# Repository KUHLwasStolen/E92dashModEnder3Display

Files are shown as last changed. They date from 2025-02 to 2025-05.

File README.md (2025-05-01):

# open-eye-drive-screen
I have the old LCD from my Creality Ender 3 Pro, which I don't need anymore, because I'm running it headless with Klipper and I want to use it to display some additional information on the dash of my BMW E92.  
Additionally the project comes with an optional/modular data logger addon, to record the sniffed telemetry data.  

The project should be compatible with all cars from the E9x series, but I only have access to an E92 for testing.  

Please make sure to not get distracted by this awesome project while on the road. Always drive with an *open-eye* :)  

On the left you can see the receiver/LCD module mounted in the car and on the right the sender/logging module mounted in the trunk of my E92.  
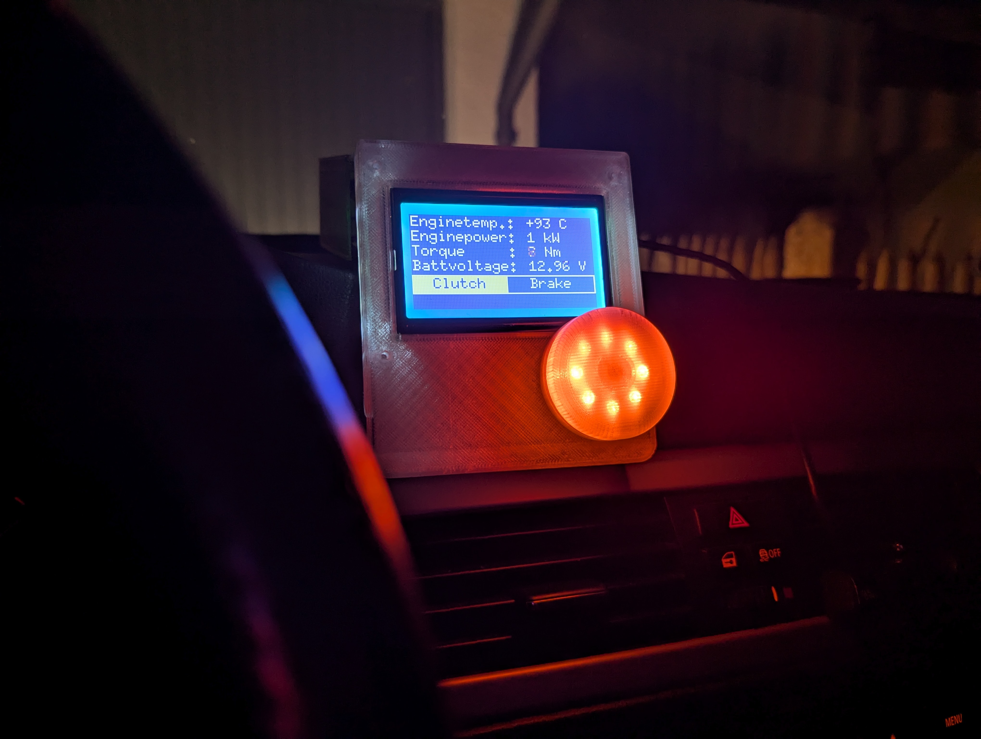
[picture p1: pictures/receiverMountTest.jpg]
picture of the receiver module mounted in the car
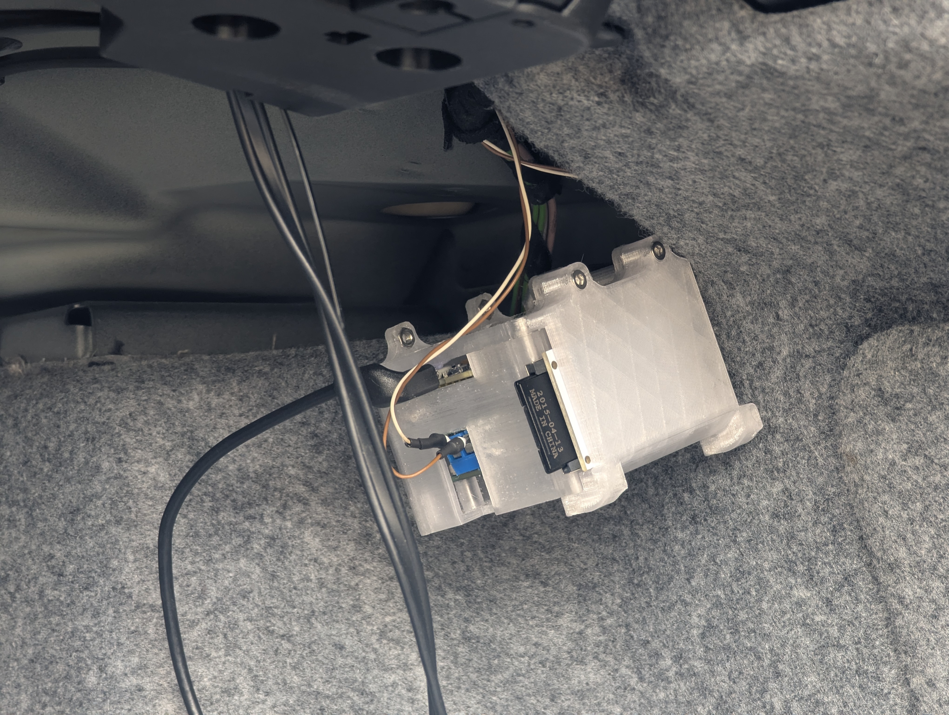
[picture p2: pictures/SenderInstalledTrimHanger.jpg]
picture of the installed sender module
   
The sender is responsible for sniffing the CAN-messages and converting them into numbers and the receiver displays those numbers. Various different pages with different numbers/representations are offered.  
The data is sent via ESP-NOW.  
The sender module is also responsible for logging the data if wished.  
The project is somewhat modular, as you can choose to omit logging capabilities and the LED ring on the encoder knob. You can still use the same code.  

Here is some logged sample data.  
The x-axis represents the time in seconds from when the drive started and the y-axis is longitudinal acceleration in m/s².
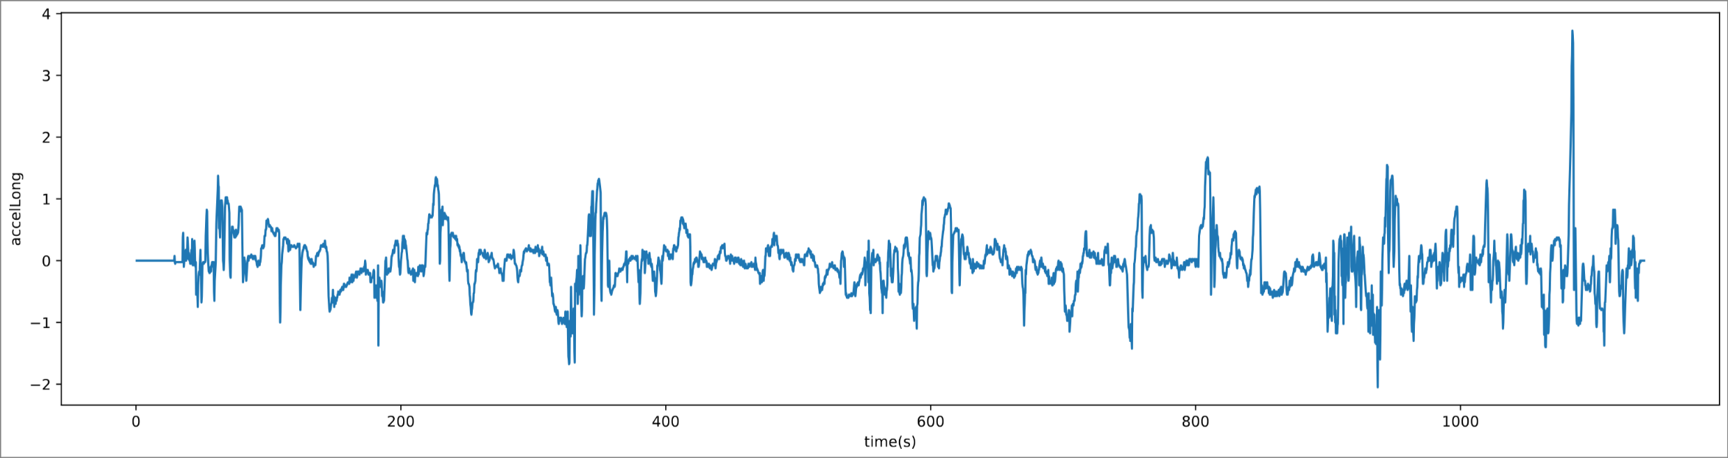
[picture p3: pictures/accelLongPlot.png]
plot of longitudinal acceleration
  
*(newer plots will automatically mark min/max values, see below)*

And this is a small part of an engine-power plot in kW.  
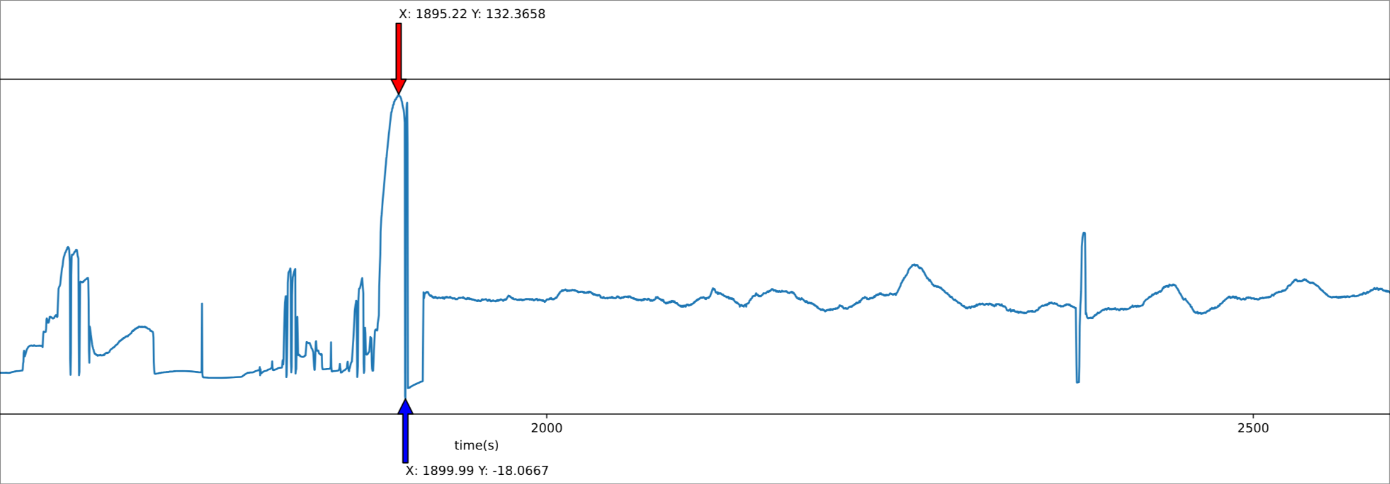
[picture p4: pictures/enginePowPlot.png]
plot of engine power data
  
Notice the annotated minimum and maximum values.  
The data plotter program will automatically do this for you and will also automatically not do this for plots where a min/max value makes no sense.  
Also notice how the minimum value is negative. This is not an error and means that the engine is slowing down the car which typically happens when you are in gear and no throttle is applied.  

## !!!Disclaimer!!!
Modifying the electrical system of your car can be **dangerous** and may void your warranty!  
Dangerous not only for your car, but also for your health!  
Before attempting any of the described modifications in this repository, **fully** read and **fully** understand everything in this README.  
I do **not** take responsibility for any type of damages, that may occur as a result of the modifications shown here.  
Do this at your own risk.

## Additions to the ecosystem  
My plan is to eventually extend this system with more devices in the car.  
Once these projects are started I will link them here.  
Planned (in that order):  
- [Wireless "scroll wheel"](https://github.com/KUHLwasStolen/open-eye-drive-scroller)
    - *BMW iDrive*-inspired controller for the LCD
    - uses a magnetic encoder to "replace" the low-quality one on the LCD
    - dedicated media buttons
- Bluetooth audio adapter
    - Bluetooth to AUX media player
    - optionally integrates into the system to be controlled by other devices and even the car (through the other devices/detected buttons presses/...)
    - (will most-likely require the "scroll wheel" for integration into the system as we cannot use Bluetooth and ESP-NOW at the same time)
- Lap timer
    - standalone lap timer using GPS
    - can record tracks, provide real-time time-delta, etc.
    - integration into system possible

## Plan
The plan is to tap into the CAN-bus somewhere on the vehicle to gather interesting information.  
From my research it seems the best bus to tap into is the KCAN (Karosserie-CAN = Body-CAN), because it contains the most interesting information.  
The speed of the bus is 100 kbit/s and it can be recognized by its twisted pair of orange/green and green wires, where OR/GN stands for CAN-HIGH and GN for CAN-LOW.  

On my vehicle the easiest place to tap into KCAN seems to be by the rear PDC (park distance control) module.  
This module might not be installed on your car.  
Alternatives include the iDrive and ultrasonic overhead alarm sensor, which are both not installed nor pre-wired on my car.  
The only problem with the PDC is that it is mounted in the trunk of the car and I want the information on the dash of my car...  

To solve this problem I want to have an ESP32 in the trunk of the car attached to the KCAN to collect data.  
Then I want another ESP32 with the LCD on the dash of the car.  
Communication between them is handled via ESP-NOW.  
This solution avoids having to run long wires through the car and enables us to mount the CAN-sniffer in the best place in each individual car.  
Another advantage is that this allows us to expand the network of devices in the car pretty easily, as we just have to add another receiver which can then handle the data as wished.  
From my testing during development, this approach has been very reliable and also responsive. I have also found similar projects using ESP-NOW, which seems to support my findings.  

#### Relevant information from KCAN
| CAN-ID | Description | Successful? |
|---|---|---|
| 0x0A8 | Engine torque to compute power, brake and clutch status | **Yes** |
| 0x0AA | Throttle position, engine RPM | **Yes** |
| 0x0C8 | Steering wheel angle/position | **Yes** |
| 0x0CE | Wheel speeds | **Yes** |
| 0x1A0 | Vehicle speed, acceleration | **Yes** |
| 0x1C2 | PDC (park distance control) sensors | **Yes** |
| 0x1D0 | Engine-temperature, (intake) air pressure | **Yes** |
| 0x1D6 | Steering wheel buttons, as not all of them do something in my car | **Yes**, except for disk button (not a top priority though) |
| 0x2F8 | Time and date information | **Yes** |
| 0x330 | Range | **Yes** |
| 0x349 | Fuel level sensors (car has two) | **Yes** |
| 0x362 | Average fuel consumption, avg. speed | **Yes** |
| 0x3B0 | Reverse gear status | **Yes** |
| 0x3B4 | Battery voltage | **Yes** |

## Execution of the plan
Tapping into the KCAN in the trunk of the car was successful.  
I have received all of the expected IDs and the data seems to be accurate/converted properly, which I still have to verify in more detail.  
**Tip:** If you are attempting the same procedure as me, remove the trim panels in the battery area, not only the battery cover.  
I did not and it was *very* tedious due to the space constraints (2 hours for splicing 2 wires).  
**ALSO: Keep away from the black/yellow twisted pair cables going to the battery. They are there for disconnecting the battery in an emergency and should not be messed with!**

At the moment I get the power for the ESP32 with the MCP from the 12V connector in the trunk.  
This connector is on when the ignition is on.  
This is a very convenient solution, but not perfect.  
Because of the (optional) logging system it would be an advantage if the ESP could stay on for a bit after the car is turned off to close the log file.  
Additionally I would like to display a summary of the drive after the car is turned off.  
I know that there are power lines in the BMW that stay on for a while after the car is locked, but I couldn't find much information about this.  
But for now, losing at max a few seconds at the end of the log is fine.  
An alternative would be a small battery backup that keeps the ESP alive for a moment after the car is stopped.  
I'm not a fan of an actual battery, but capacitors might do the trick(?).  

**Attention:** When I first tried to access the KCAN the car was throwing **all** sorts of error messages at me.  
I assume that the cause for this was, that the ESP was sending acknowledgement messages to the car when a message was received.  
Seemingly the car does not like this **at all**. Setting the MCP mode to listen-only seems to fix this though.

## Schematic
The KiCAD schematic in this repository serves a purely symbolic purpose!  
I am not an expert at designing circuits and just want to give you a general idea about the correct wiring.  
Any constructive input on how to improve the schematic is greatly appreciated!

## 3D Models
3D-printable enclosures and accessories can be found [here](cad/exports).  
(Yes, most slicers are able to use .step files, most people are not aware of this).  
All of the models are in their perfect printing orientation and do not *need* supports.  
The only place where you might need a tiny bit of support is [this](cad/exports/SenderModels/Enclosure_bottom.step) model, on the small, straight overhang for the screw terminal.  
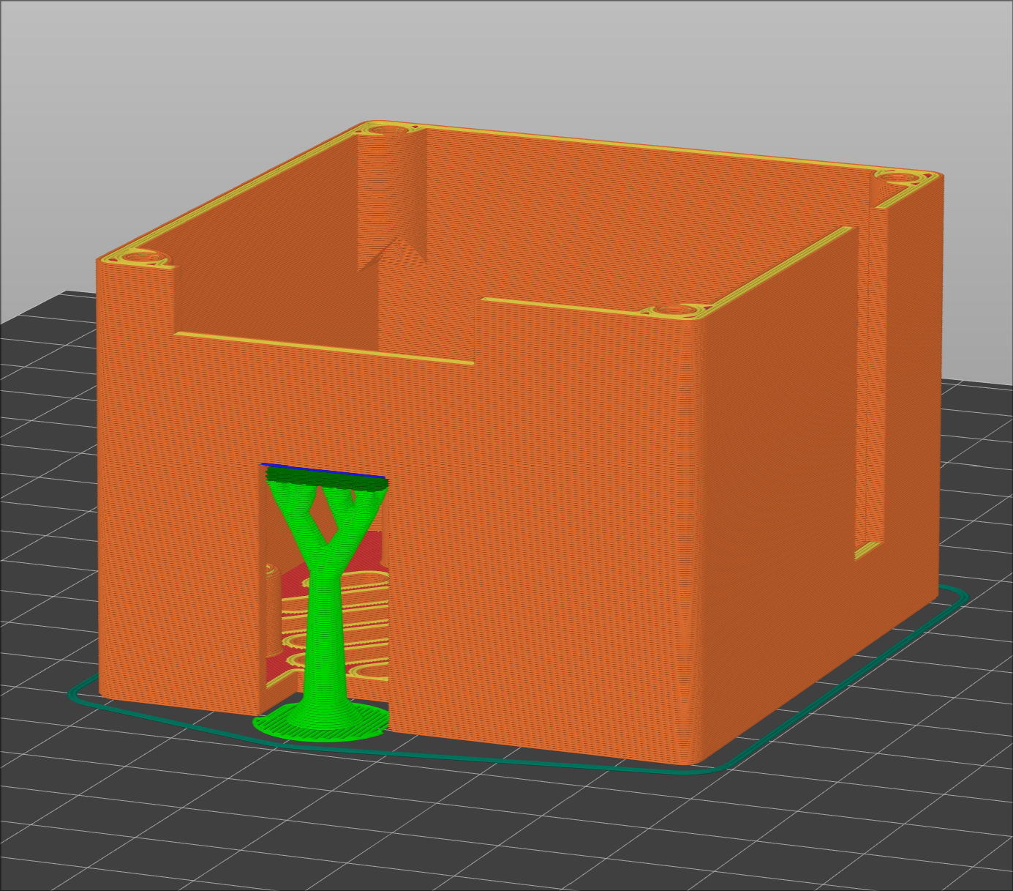
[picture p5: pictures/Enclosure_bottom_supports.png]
Enclosure_bottom support example
  

The models include a lot of screw holes which are made to be tapped.  
Ideally you would use a thread tap for this, but you can also probably just cut the thread by screwing in the bolt that is supposed to go there.  
Tapped threads in 3D-prints are surprisingly strong and durable. They are a great way to easily put threads in all kinds of places/orientations.  

## Logging
As mentioned above, the project offers optional logging capability.  
Data is stored to a SD-card in .csv format. For space reasons non-floating-point values in HEX, so not really human readable or ready to easily plot.  
The project offers a C++ program to convert the data back into decimal form, which is located [here](logging).  

*Usage:*  
```
# first compile the program (only needed once)
g++ dataConverter.cpp -o dataConverter

# then convert your log
./dataConverter [your_log.csv]
```

Then you can plot the converted data into a PDF with the python script in the same folder.  
The x-axis will always be the time in seconds since the drive started.  

*Usage:*
```
# index: 0 -> time(s), 1 -> clutchPressed, 2-> brakePressed, ...
python dataPlotter.py [your_log_converted.csv] [column index to plot on y]

# or to plot all columns and export them into separate files
python dataPlotter.py [your_log_converted.csv] all
```

## Hardware
Here you can find a list of materials needed for the project.  
Note that this list always reflects the current state of the project and might change over time.  
Also note that links to products are only meant as a guide what to look for and what/where ***I*** bought them.  
Depending on your location/preference there might be better/cheaper alternatives.  
You can buy the components wherever you want as long as they are the same/similar enough.  
I am in no way affiliated with the linked sellers and can in no way guarantee their reliability!  

| Description | Quantity | Notes | Link |
|---|---|---|---|
| ESP32-WROOM-32 dev module | 2 | most other ESPs should also work, just connect everything to the right GPIOs | https://www.az-delivery.de/en/products/esp32-developmentboard?_pos=1&_psq=esp32+n&_ss=e&_v=1.0 |
| MCP2515 CAN bus module | 1 | yes, odd choice in combination with ESP32, I just use what I already had | https://www.az-delivery.de/en/products/mcp2515-can-bus-modul?_pos=1&_psq=MCP2515&_ss=e&_v=1.0 |
| Ender 3 (Pro) LCD | 1 | also an odd choice but, again, I already had one from my 3D printer; I will not leave a link where to buy one as this doesn't make much sense, it would be easier/cheaper to just implement support for other types of displays, which is also planned for the future! | |
| (SD card module) | (1) | OPTIONAL: this is an optional feature to log the collected telemetry, this can also be added later and doesn't need a code update | https://www.velleman.eu/products/view/sd-card-logging-shield-for-arduino-2-pcs-vma304/?id=435522&lang=en (I have exactly these, didn't buy them there though) |
| (SD card) | (1) | if you want to use the optional data logger you will need an SD card |  |
| (WS2812 LED ring 8 pixels) | (1) | OPTIONAL: used to light up the encoder knob on the LCD and play animations | https://www.az-delivery.de/en/products/led-ring-ws2812-5050-rgb?variant=44246024978699 |
| 10k Ohm resistor | 3 | used as pullups, similar values may also work |  |
| 560 Ohm resistor | 2 | used for the transistors, similar values may also work |  |
| (330 Ohm resistor) | 1 | used for the optional LED ring, similar values also work |  |
| BC547 transistor | 1 | used to switch LCD on/off, can be replaced by a similar NPN |  |
| S8550 transistor | 1 | used to switch LCD on/off, can be replaced by a similar PNP |  |
| M3x6 bolts | 0-4 | Depending on config: used to mount the trim hook, SD card cover on the bottom |  |
| M3x8 bolts | 4-7 | Depending on config: used for the SD card breakout board, mounting the MCP |  |
| M3x10 bolts | 0-2 | Depending on config: used to hold SD card cover |  |
| M3x12 bolts | 4-5 | Used for attaching the sender lid and the optional LED ring cover/holder |  |
| M3 hex nuts | 0-9 | Depending on config: used for the SD card breakout board, accessory mounting |  |
| (Jumper) wires | 1 metric ton | jumper wires for testing on a bread board |  |
| Perf board + accessories |  | for the final implementation in the enclosures in the car | https://www.amazon.com/Smraza-Soldering-Electronic-Compatible-Prototype/dp/B07NM68FXK/ref=sr_1_3 (I bought something similar) | 

## References
Here you can find some links with useful information in relation to this project.  

**CAN bus related**
| Description | Link |
|---|---|
| This thread contains **A LOT** of information about the E9x KCAN, but it is also kind of all over the place so you have to dig a bit | https://www.e90post.com/forums/showthread.php?t=177272 |
| Awesome work on decoding the BMW K-CAN bus system. But watch out, this work wasn't done on an E9X so CAN IDs and formulas *may* differ but should largely be the same. | https://www.loopybunny.co.uk/CarPC/k_can.html |
| Another project decoding the BMW CAN bus, although it says PT-CAN I found a lot of overlap between the K- and PT-CAN | https://github.com/HeinrichG-V12/E65_ReverseEngineering |
| A table I found with CAN bus IDs of the E9X and their meanings | https://github.com/kmalinich/node-bmw-ref/blob/master/canbus/e90-tool32-ids.csv |

**Hardware related**
| Description | Link |
|---|---|
| My source for the Ender3 LCD pinout | https://github.com/rfblock/ender3-lcd-arduino |
| Library used to drive LCD (can be downloaded via Arduino IDE) | https://github.com/olikraus/u8g2 |
| Library used to drive MCP2515 module (can be downloaded via Arduino IDE) | https://github.com/Seeed-Studio/Seeed_Arduino_CAN |
| Library used to drive the LED ring (can be downloaded via Arduino IDE) | https://github.com/adafruit/Adafruit_NeoPixel |

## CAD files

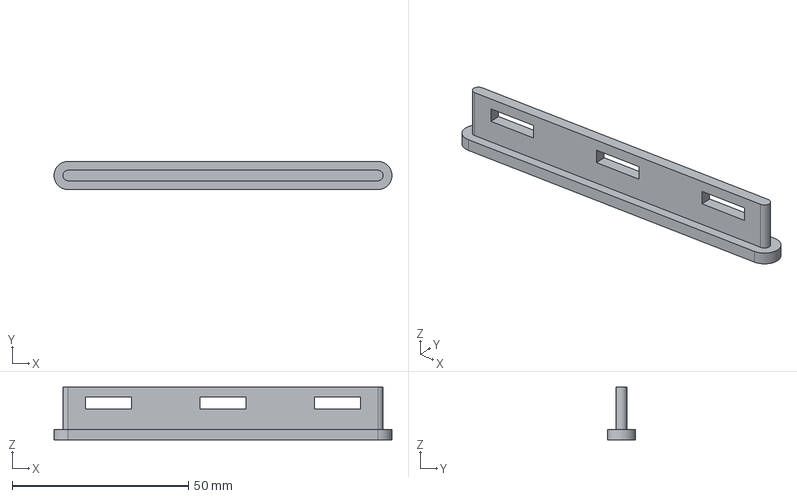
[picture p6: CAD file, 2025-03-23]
cad/exports/ReceiverModels/velcro_ties_mount.step
95.9 x 8.00 x 15.0 mm

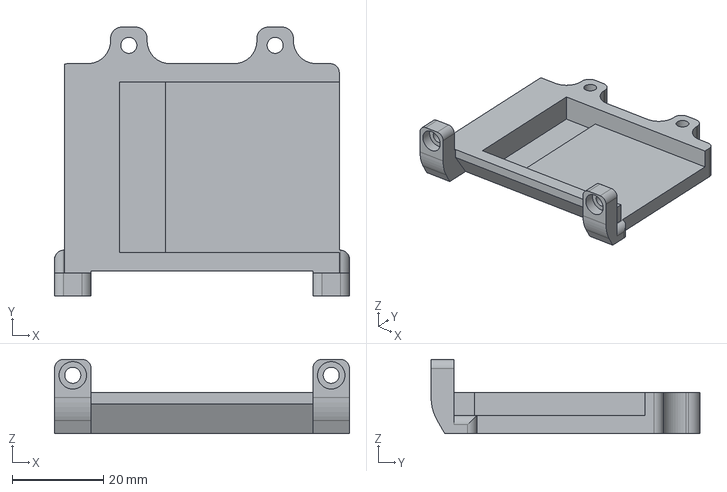
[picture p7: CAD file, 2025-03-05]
cad/exports/SenderModels/SD_cover.step
64.5 x 58.8 x 16.3 mm

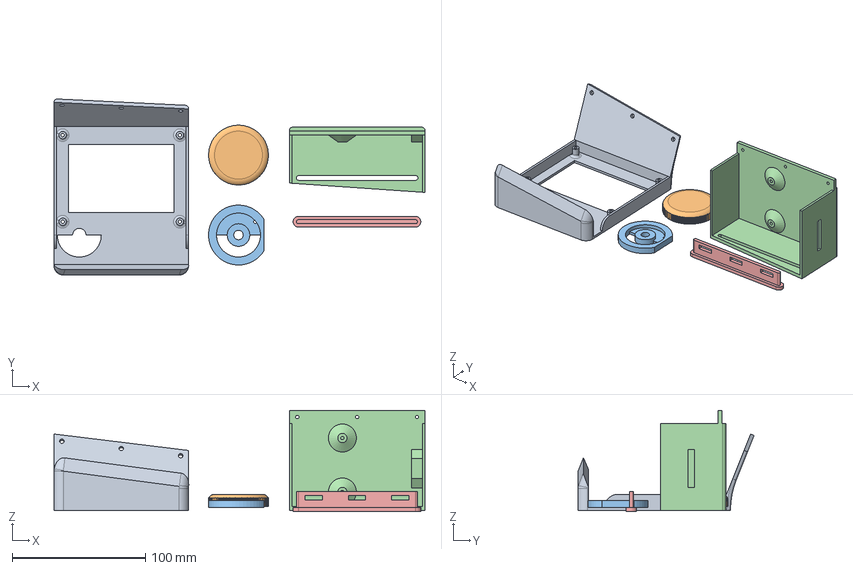
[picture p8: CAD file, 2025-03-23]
cad/ReceiverModels/ReceiverModels.FCStd
278.5 x 132.1 x 76.0 mm
LCD mount
Encoder knob
LED ring holder
Controller enclosure
Controller mounting velcro ties

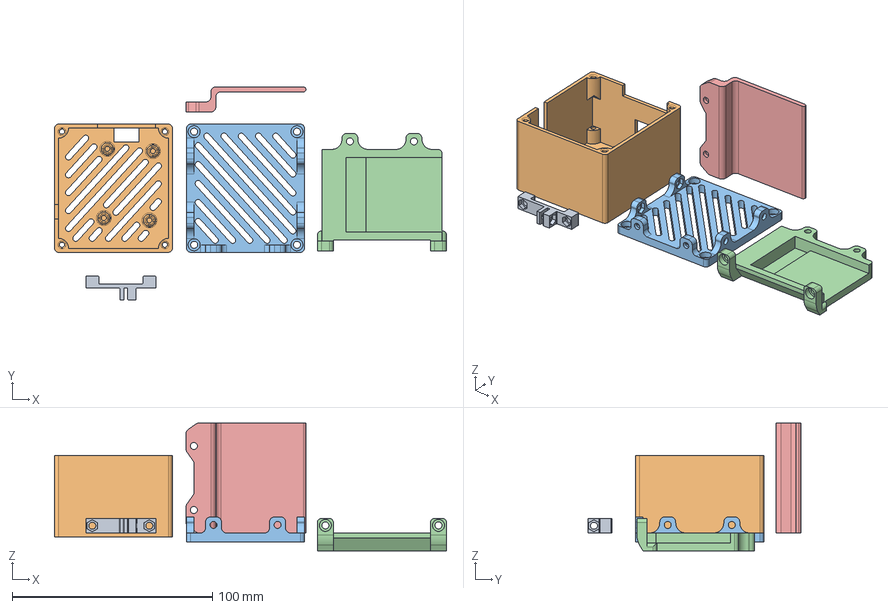
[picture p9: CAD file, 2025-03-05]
cad/SenderModels/SenderModels.FCStd
195.9 x 106.5 x 63.9 mm
SD breakout holder
Enclosure bottom
Enclosure top
SD cover
E92 trim hanger

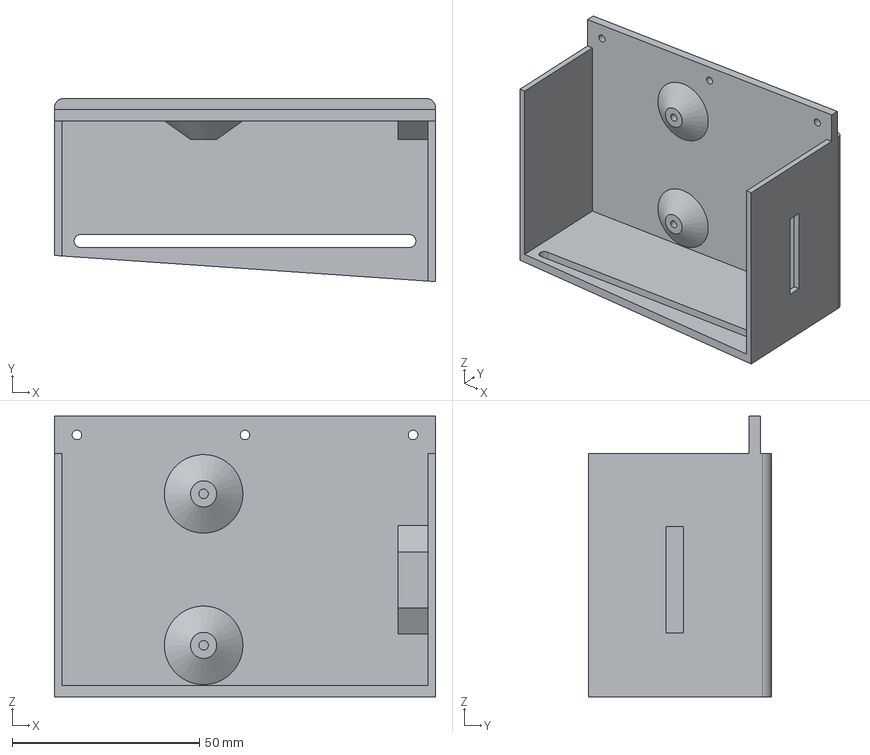
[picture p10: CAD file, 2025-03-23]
cad/exports/ReceiverModels/controller_enclosure.step
101.9 x 49.0 x 75.0 mm

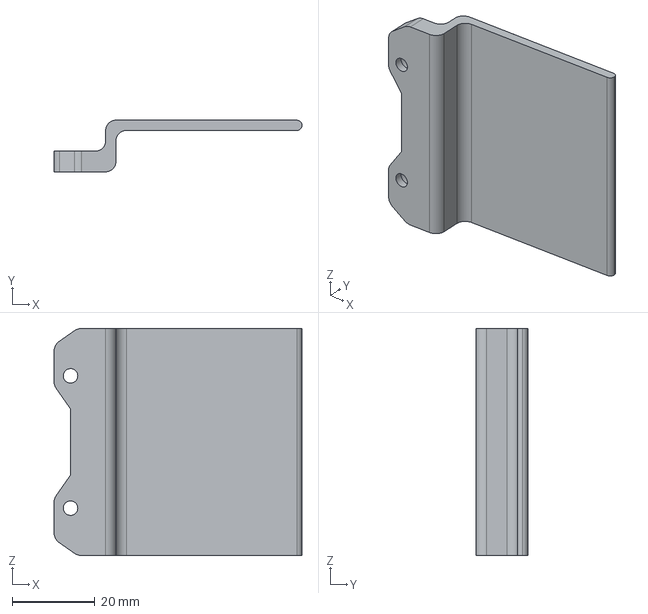
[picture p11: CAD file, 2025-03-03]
cad/exports/SenderModels/E92_trim_hanger.step
60.0 x 12.5 x 54.9 mm

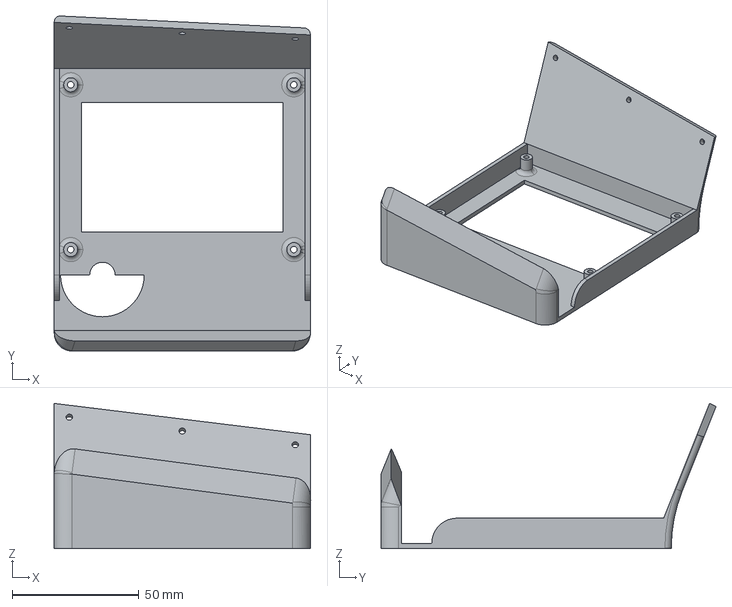
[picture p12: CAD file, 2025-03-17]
cad/exports/ReceiverModels/LCD_mount.step
101.2 x 132.1 x 57.3 mm

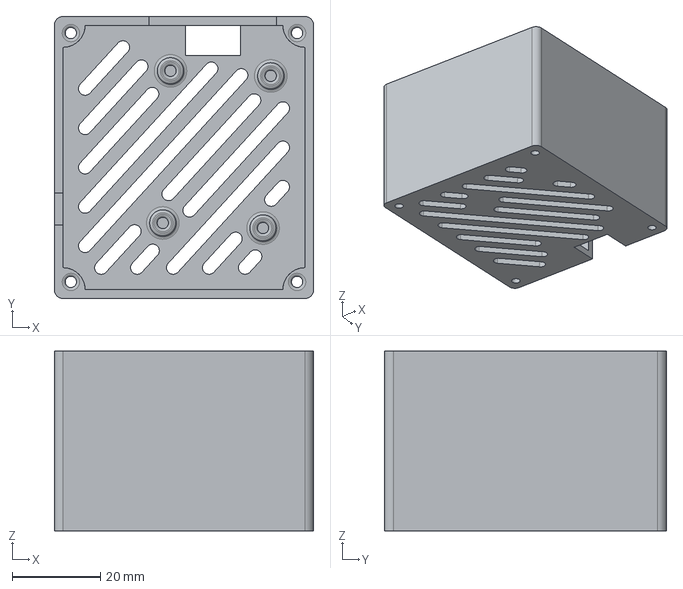
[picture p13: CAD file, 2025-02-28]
cad/exports/SenderModels/Enclosure_bottom.step
58.9 x 64.1 x 40.8 mm

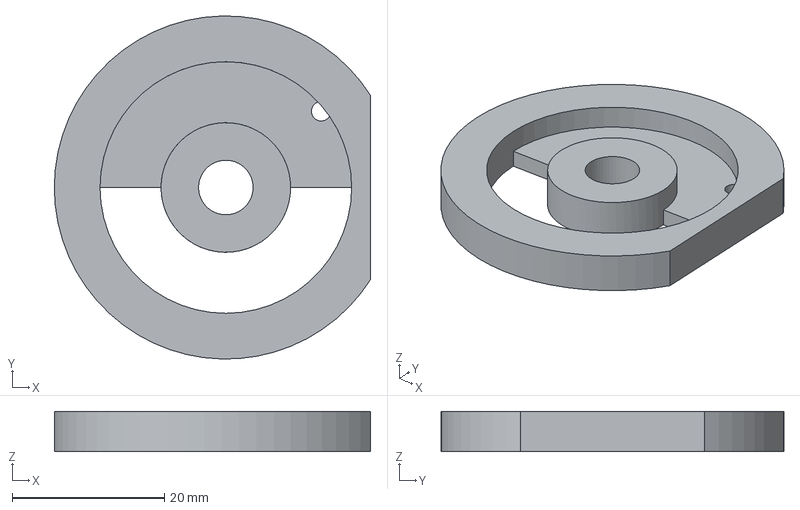
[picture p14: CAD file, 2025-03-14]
cad/exports/ReceiverModels/LED_ring_holder.step
41.5 x 45.0 x 5.25 mm

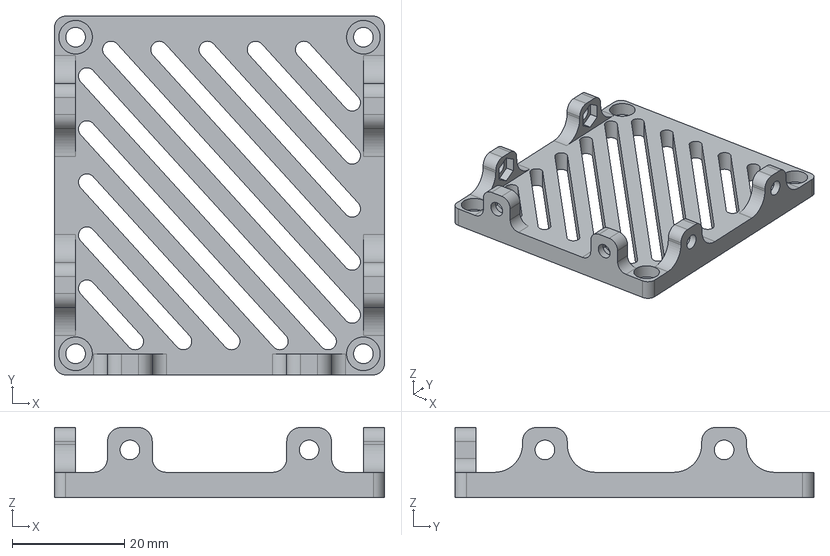
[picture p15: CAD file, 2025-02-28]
cad/exports/SenderModels/Enclosure_top.step
58.9 x 64.1 x 12.5 mm

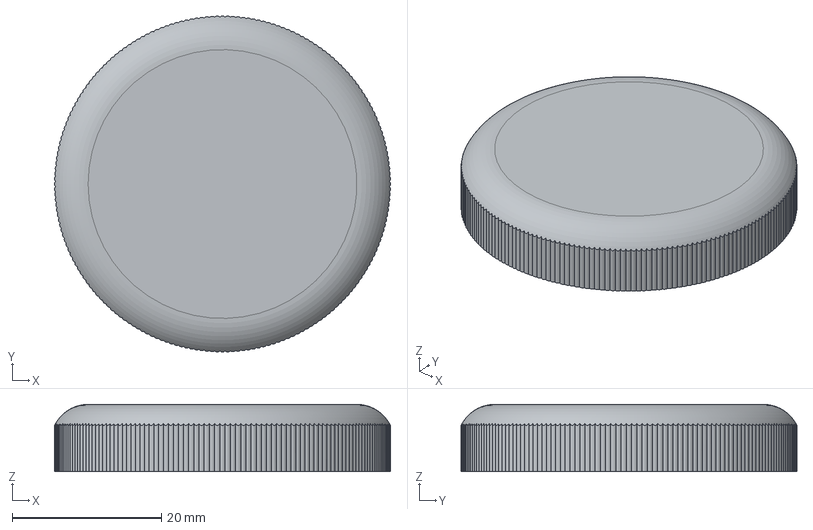
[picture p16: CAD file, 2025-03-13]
cad/exports/ReceiverModels/encoder_knob.step
45.0 x 45.0 x 9.00 mm

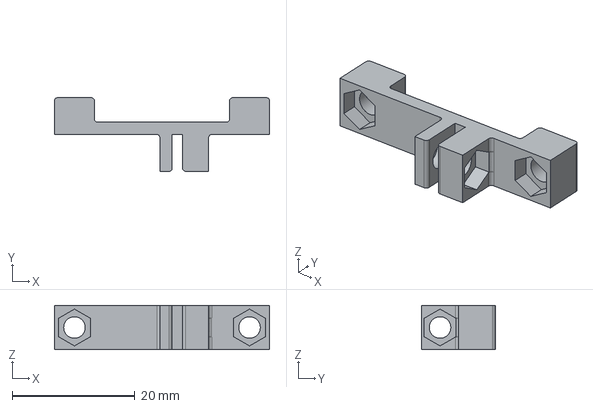
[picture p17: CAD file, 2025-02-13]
cad/exports/SenderModels/SD_holder.step
35.0 x 12.0 x 7.20 mm

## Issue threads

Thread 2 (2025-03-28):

Weird rendering behaviour

KUHLwasStolen, 2025-03-28:
The first line of the selector screen is weirdly rendered if the standard LCD screen setting is not the mixed dash.
Switching the LCD off and on again fixes this.

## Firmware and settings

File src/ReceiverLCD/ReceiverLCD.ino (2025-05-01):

#include <esp_now.h>
#include <WiFi.h>
#include <SPI.h>
#include <U8g2lib.h>
#include <Adafruit_NeoPixel.h>
#include <Preferences.h>

#define EN2_PIN 23
#define EN1_PIN 22
#define ENC_PIN 21

#define LCD_POWER_PIN 13
#define LCD_CS_PIN 15
#define LCD_SCK_PIN 14
#define LCD_MOSI_PIN 27

#define LED_RING_PIN 26
#define PIXEL_COUNT 8

// ## LCD related
#define LCD_OFF_STATE 0
#define MIXED_DASH_STATE 1
#define SPEED_ACCEL_STATE 2
#define FUEL_INFO_STATE 3
#define PDC_SENSOR_STATE 4

U8G2_ST7920_128X64_F_SW_SPI u8g2(U8G2_R0, LCD_SCK_PIN, LCD_MOSI_PIN, LCD_CS_PIN);
uint8_t lcdState = 1; // see state numbers and meanings above
uint8_t standardLcdState = lcdState; // used for displaying/setting standard state
#define LCDSTATE_COUNT 5 // number of available states of the lcd (another one is added automatically, selector screen)
#define MAX_LINES 7 // max number of selectable line
uint8_t selectedLine = 0; // for screens that use user selection

// ## LED ring related
Adafruit_NeoPixel ledRing(PIXEL_COUNT, LED_RING_PIN, NEO_GRB + NEO_KHZ800);
const uint32_t standardColor = ledRing.Color(0xFE, 0x81, 0x06);
uint8_t ledRingState = 1; // 0 = off, 1 = static standard color, ... (refer to updateLedRing() function)
#define LEDSTATE_COUNT 3

uint8_t ledBrightness = 70; // brightness of led ring from 0 (off) to 255 (full), going too high is not recommended because of power draw and danger of being blinded
const uint8_t maxLedBrightness = 140; // limits the brightness of the LED ring to a reasonable level (used for adjusting via LCD)
const uint8_t ledBrightnessStep = 7; // steps for increasing ledBrightness

#define MAXPOW_RPM 4000 // used for shift indicator, adjust this for your own car, refer to spec sheets online or use the data logger of the sender module to find this point
#define SHIFTINDICATOR_START 2000 // this is the rpm where the shift indicator will illuminate the first light
// individual color steps of the led ring gear shift indicator
const uint32_t gearShiftColors[PIXEL_COUNT] = {ledRing.Color(0x2E, 0xFF, 0x11), ledRing.Color(0xB6, 0xFF, 0x00), ledRing.Color(0xFF, 0xF6, 0x00), ledRing.Color(0xFF, 0xE0, 0x30), ledRing.Color(0xFF, 0xE0, 0x30), ledRing.Color(0xFF, 0xD5, 0x00), ledRing.Color(0xFF, 0x60, 0x21), ledRing.Color(0xFF, 0x23, 0x23)};
bool rpmBlinkOn = false;
uint64_t lastBlinkChange = 0;

// ## Preferences/settings related
Preferences preferences;
/* saved settings:
standardValues {
  lcdState: uint8_t
  ledRingState: uint8_t
  ledBrightness: uint8_t
}                         */

// ## Task handles
TaskHandle_t RenderingTask;
TaskHandle_t UserInputTask;

// ## ESP-NOW related
#define ESP_NOW_CHANNEL 1 // if you change this you have to change this on all devices

typedef struct kcan_data_t {
  bool clutchPressed;
  bool brakePressed;
  bool reversed;
  uint8_t steeringWheelButtons; // each bit one button (use functions below): 2^0=VolumeUp, 2^1=VolumeDown, 2^2=UpButton, 2^3=DownButton, 2^4=TelephoneButton, 2^5=VoiceButton, 2^6=RotateButton, 2^7=DiskButton
  uint8_t PDCsensors[8]; // in cm, order: rear-L, rear-L2, rear-R2, rear-R, front-L, front-L2, front-R2, front-R
  int16_t engineTemp; // in celcius
  int16_t wheelSpeeds[4]; // in km/h (might depend on car settings), order: front-L, front-R, rear-L, rear-R
  uint16_t speed; // in km/h (might depend on car settings)
  uint16_t engineRpm;
  uint16_t range; // in km
  uint16_t airPressEngine; // in hPa
  float fuelLevel1; // in liter
  float fuelLevel2; // in liter
  float engineTorque; // in Nm, can be negative!
  float batteryVoltage; // in volts
  float avgConsumption; // in l/100km (dependent on the car settings)
  float avgSpeed; // in km/h (dependent on the car settings)
  float throttlePercentage; // throttle from 0 (foot off paddle) to 1 (flat), also includes throttle input from cruise control
  float steeringPosition; // +1 -> fully (600°) to the left, 0 -> centered, -1 -> fully (600°) to the right
  float accelerationLong; // in m/s²
  float accelerationCross; // in m/s²
} kcan_data_t;

typedef struct sd_data_t {
  uint16_t usedMiB;
  uint16_t totalMiB;
} sd_data_t;

typedef struct scroller_data_t {
  int8_t rotation; // positive -> clockwise steps, negative -> counter-clockwise steps
  uint8_t buttons; // each bit one button (use functions below): 2^0=pause, 2^1=next, 2^2=prev, 2^3=click, 2^4=right, 2^5=left
} scroller_data_t;

kcan_data_t kcan_data;
sd_data_t sd_data = {0, 0};
scroller_data_t scroller_data = {0};

// executed when data is received
void OnDataRecv(const uint8_t * mac, const uint8_t * incomingData, int32_t len) {
  if(len == sizeof(kcan_data)) {
    memcpy(&kcan_data, incomingData, sizeof(kcan_data));
  } else if(len == sizeof(sd_data)) {
    memcpy(&sd_data, incomingData, sizeof(sd_data));
  } else if(len == sizeof(scroller_data)) {
    memcpy(&scroller_data, incomingData, sizeof(scroller_data));
  }
}


void setup() {
  Serial.begin(115200);

  pinMode(LCD_POWER_PIN, OUTPUT);
  pinMode(ENC_PIN, INPUT);
  pinMode(EN1_PIN, INPUT);

  digitalWrite(LCD_POWER_PIN, HIGH); // turn on lcd
  

  u8g2.begin(); // initialize lcd
  u8g2.setFont(u8g2_font_6x10_mr);
  u8g2.clear();


  // Setup WIFI mode and print MAC address
  WiFi.mode(WIFI_MODE_STA);
  WiFi.setChannel(ESP_NOW_CHANNEL);
  while (!WiFi.STA.started()) {
    delay(100);
  }
  Serial.print("Receiving data at: ");
  Serial.println(WiFi.macAddress());

  // Init ESP-NOW
  if (esp_now_init() != ESP_OK) {
    Serial.println("Error initializing ESP-NOW! Restarting in 250");
    displayErrorMessage("ESP-NOW init failed!");
    delay(250);
    ESP.restart();
  }

  // register callback function
  esp_now_register_recv_cb(esp_now_recv_cb_t(OnDataRecv));
  Serial.println("Succesfully initialized ESP-NOW");
  
  Serial.print("Expecting ESP-NOW messages at a size of: ");
  Serial.println(sizeof(kcan_data));

  ledRing.begin(); // initialize LEDs
  ledRing.show(); // initialize pixels to off

  // get last saved preferences
  preferences.begin("standardValues", true);
  lcdState = preferences.getUChar("lcdState", lcdState);
  standardLcdState = lcdState;
  ledRingState = preferences.getUChar("ledRingState", ledRingState);
  ledBrightness = preferences.getUChar("ledBrightness", ledBrightness);
  preferences.end();

  // display BMW logo and 1 ms later start ledRing animation
  showStartupLogo(1);

  for(uint8_t i = 0; i < 3 * PIXEL_COUNT; i++) {
    ledRing.clear();
    ledRing.setBrightness(ledBrightness);
    ledRing.setPixelColor(i % PIXEL_COUNT, ledRing.gamma32(standardColor));
    ledRing.show();

    delay(83);
  }

  xTaskCreatePinnedToCore(
                    renderingTaskCode,    // Task function
                    "renderingTask",      // name of task
                    10000,                // Stack size of task
                    NULL,                 // parameter of the task
                    2,                    // priority of the task
                    &RenderingTask,       // Task handle to keep track of created task
                    1);                   // pin task to core 1

  xTaskCreatePinnedToCore(
                    userInputTaskCode,    // Task function
                    "userInputTask",      // name of task
                    10000,                // Stack size of task
                    NULL,                 // parameter of the task
                    1,                    // priority of the task
                    &UserInputTask,       // Task handle to keep track of created task
                    1);                   // pin task to core 1
}

 
void loop() {
}


void userInputTaskCode(void * params) {
  Serial.print("User input task running on core ");
  Serial.println(xPortGetCoreID());

  bool pressed = false;

  while(1) {
    // Encoder button
    if(digitalRead(ENC_PIN) == 0 || clickPressed()) {
      pressed = true;
      Serial.println("Encoder/Click button pressed");
      
      // only need to handle states with special cases
      switch(lcdState) {
        case LCDSTATE_COUNT: // selector screen
          switch(selectedLine) {
            case 0: // "Next"
              lcdState = 1; // go back to the first page
            break;

            case 1: // "LCD off"
              Serial.println("Turning off LCD");
              lcdState = 0;
              digitalWrite(LCD_POWER_PIN, LOW);
            break;

            case 2: // "LED mode"
              Serial.println("Switching LED ring state");
              ledRingState = (ledRingState + 1) % LEDSTATE_COUNT;
            break;

            case 3: // "LED brightness"
              Serial.println("Changing LED ring brightness");
              ledBrightness = (ledBrightness + ledBrightnessStep) % (maxLedBrightness + ledBrightnessStep);
            break;

            case 4: // standard LCD state
              Serial.println("Changing standard LCD state");
              standardLcdState = (standardLcdState + 1) % LCDSTATE_COUNT;
            break;

            case 5: // save settings
              Serial.println("Saving settings");
              preferences.begin("standardValues", false);
              preferences.putUChar("lcdState", standardLcdState);
              preferences.putUChar("ledRingState", ledRingState);
              preferences.putUChar("ledBrightness", ledBrightness);
              preferences.end();
            break;

            case 6: // Restart ESP
              Serial.println("Rebooting...");
              ESP.restart();
            break;
          }
        break;
        
        default:
          nextScreen();
      }
    }


    // Encoder rotate (no direction detection only rotate, because direction is VERY inconsistent because of low-quality encoder on the LCD)
    if(digitalRead(EN1_PIN) == 0) {
      pressed = true;
      Serial.println("Rotated");
      selectedLine = (selectedLine + 1) % MAX_LINES;
    }


    // Steering wheel buttons
    if(kcan_data.steeringWheelButtons != 0) {
      pressed = true;

      if(volumeUpPressed()) {
        Serial.println("Volume up (steering wheel) pressed");
      }
      if(volumeDownPressed()) {
        Serial.println("Volume down (steering wheel) pressed");
      }
      if(upPressed()) {
        Serial.println("Up button (steering wheel) pressed");
      }
      if(downPressed()) {
        Serial.println("Down button (steering wheel) pressed");
      }
      if(telephonePressed()) {
        Serial.println("Telephone button (steering wheel) pressed");
      }
      if(voicePressed()) {
        Serial.println("Voice button (steering wheel) pressed");
      }
      if(rotatePressed()) {
        Serial.println("Rotate button (steering wheel) pressed");
      }
      if(diskPressed()) {
        Serial.println("Disk button (steering wheel) pressed");
      }
    }


    // Scroller module events
    if(scroller_data.rotation != 0) {
      if(scroller_data.rotation < 0 && -scroller_data.rotation > selectedLine) {
        selectedLine = 0;
      } else {
        selectedLine = min(MAX_LINES - 1, selectedLine + scroller_data.rotation);
      }

      scroller_data.rotation = 0;
    }

    if(scroller_data.buttons != 0) {
      pressed = true;

      if(rightPressed()) {
        nextScreen();
      }
      if(leftPressed()) {
        prevScreen();
      }

      scroller_data.buttons = 0;
    }

    delay(pressed ? 400 : 1); // if pressed avoid multiple triggers, if not yield
    pressed = false;
  }
}


void renderingTaskCode(void * params) {
  Serial.print("Rendering task running on core ");
  Serial.println(xPortGetCoreID());

  uint8_t lastLcdState = lcdState;
  bool lastReversed = kcan_data.reversed;

  while(1) {
    if(lcdState != PDC_SENSOR_STATE
        && (kcan_data.reversed == true && lastReversed == false)) {

      lastLcdState = lcdState;
      lcdState = PDC_SENSOR_STATE;

    } else if(lcdState == PDC_SENSOR_STATE
              && (kcan_data.reversed == false && lastReversed == true)) {

      lcdState = lastLcdState;
    }
    
    lastReversed = kcan_data.reversed;

    updateDisplay();
    updateLedRing();
    delay(55); // ~18 refreshes/s
  }
}


// displays the current vehicle information
void updateDisplay() {
  switch(lcdState) {
    case LCD_OFF_STATE: break;
 
    case MIXED_DASH_STATE:
      drawMixedDash();
    break;
    
    case SPEED_ACCEL_STATE:
      drawSpeeds();
    break;

    case FUEL_INFO_STATE:
      drawFuelInfo();
    break;

    case PDC_SENSOR_STATE:
      drawPDCsensors();
    break;

    case LCDSTATE_COUNT:
      drawSelectorScreen();
    break;
  }
}

// updated the LED ring according to current wish
void updateLedRing() {
  ledRing.clear(); // turn off everything
  ledRing.setBrightness(ledBrightness); // set current brightness

  switch(ledRingState) {
    // ring off, no need to do anything
    case 0: break;

    // static standard color
    case 1:
      ledRing.fill(ledRing.gamma32(standardColor), 0, PIXEL_COUNT);
    break;

    // rpm reactive shift indicator
    case 2:
      // complete red if rpm >= optimal shift rpm
      if(kcan_data.engineRpm > MAXPOW_RPM) {
        if(!rpmBlinkOn && millis() - lastBlinkChange >= 200) {
          rpmBlinkOn = true;
          lastBlinkChange = millis();
        } else if(rpmBlinkOn && millis() - lastBlinkChange >= 400) {
          rpmBlinkOn = false;
          lastBlinkChange = millis();
        }

        if(rpmBlinkOn) ledRing.fill(ledRing.gamma32(gearShiftColors[7]), 0, PIXEL_COUNT);
      } else {    // fill ring according to steps specified
        uint16_t rpmSteps = (uint16_t)(abs((MAXPOW_RPM - SHIFTINDICATOR_START) / PIXEL_COUNT));
        rpmBlinkOn = false;

        for(uint8_t i = 0; i < PIXEL_COUNT; i++) 
          if(kcan_data.engineRpm >= SHIFTINDICATOR_START + (rpmSteps * i)) 
            ledRing.setPixelColor(i, ledRing.gamma32(gearShiftColors[i]));
      }

    break;
  }

  ledRing.show(); // update changes
}


// ### Display rendering helper functions ###
void getEngineTempStr(char* tempStr) {
  sprintf(tempStr, "%+d C", kcan_data.engineTemp);
}

void getEnginePowerStr(char* powStr) {
  float enginePower = ((float)kcan_data.engineRpm * kcan_data.engineTorque * ((2.0f * PI) / 60.0f)) / 1000.0f;
  sprintf(powStr, "%d kW", (int)round(enginePower));
}

void getEngineTorqueStr(char* torqueStr) {
  sprintf(torqueStr, "%d Nm", (int)round(kcan_data.engineTorque));
}

void getBatteryVoltageStr(char* voltStr) {
  sprintf(voltStr, "%.2f V", kcan_data.batteryVoltage);
}

void getFuelLevelStr(char* fuelStr, uint8_t fuelIndex) {
  switch(fuelIndex) {
    case 1:
      sprintf(fuelStr, "%.1f l", kcan_data.fuelLevel1);
    break;

    case 2:
      sprintf(fuelStr, "%4.1f l", kcan_data.fuelLevel2);
    break;

    default: sprintf(fuelStr, "N/A");
  }
}

void getFuelPercentageStr(char* fuelStr) {
  sprintf(fuelStr, "%4.1f%%", ((kcan_data.fuelLevel1 + kcan_data.fuelLevel2) * 100.0f) / (2.0f * 62.0f));
}

void getRangeStr(char* rangeStr) {
  sprintf(rangeStr, "%d km", kcan_data.range);
}

void getAvgConsumptionStr(char* consStr) {
  sprintf(consStr, "%.1f l/100km", kcan_data.avgConsumption);
}

void getAvgSpeedStr(char* speedStr) {
  sprintf(speedStr, "%.1f km/h", kcan_data.avgSpeed);
}

void getPDCstr(char* pdcStr, uint8_t index, bool displayedLeft) {
  sprintf(pdcStr, displayedLeft ? "%d cm": "%3d cm", kcan_data.PDCsensors[index]);
}

void getSpeedStr(char* speedStr, uint8_t index, bool displayedLeft) {
  sprintf(speedStr, displayedLeft ? "%d" : "%3d", index < 4 ? kcan_data.wheelSpeeds[index] : kcan_data.speed);
}

void getLedRingStateStr(char* stateStr) {
  switch(ledRingState) {
    case 0:
      sprintf(stateStr, "        off");
    break;

    case 1:
      sprintf(stateStr, "     static");
    break;

    case 2:
      sprintf(stateStr, "shift light");
    break;
  }
}

void getLedRingBrightnessPercentageStr(char* percentageStr) {
  sprintf(percentageStr, "%3d%%", (int)(float(ledBrightness * 100) / float(maxLedBrightness)));
}

void getSdCardStr(char* sdStr) {
  sprintf(sdStr, "%5u/%5u MiB", sd_data.usedMiB, sd_data.totalMiB);
}

void getLcdStateStr(char* stateStr, uint8_t index) {
  switch(index) {
    case LCD_OFF_STATE:
      sprintf(stateStr, "      off");
    break;
 
    case MIXED_DASH_STATE:
      sprintf(stateStr, "    mixed");
    break;
    
    case SPEED_ACCEL_STATE:
      sprintf(stateStr, "accel/sp.");
    break;

    case FUEL_INFO_STATE:
      sprintf(stateStr, "     fuel");
    break;

    case PDC_SENSOR_STATE:
      sprintf(stateStr, "      PDC");
    break;

    default: sprintf(stateStr, "      N/A");
  }
}


// ### Logic helper functions ###
//  ## Switch LCD screen ##
void nextScreen() {
  if(lcdState == 0) {
    turnOnLcd();
  }

  lcdState = max(1, (lcdState + 1) % (LCDSTATE_COUNT + 1));
}

void prevScreen() {
  if(lcdState == 0) {
    turnOnLcd();
  }

  if(lcdState == 0 || lcdState == 1) {
    lcdState = LCDSTATE_COUNT;
    return;
  }

  lcdState -= 1;
}

void turnOnLcd() {
  Serial.println("Turning on LCD");
  digitalWrite(LCD_POWER_PIN, HIGH);
  delay(30); // give it a bit of time to turn on again
  u8g2.clear(); // clear display as sometimes there are artifacts when turning back on
}

//  ## Convert steeringWheelButtons into bools ##
bool volumeUpPressed() {
  return kcan_data.steeringWheelButtons % 2;
}

bool volumeDownPressed() {
  return (kcan_data.steeringWheelButtons >> 1) % 2;
}

bool upPressed() {
  return (kcan_data.steeringWheelButtons >> 2) % 2;
}

bool downPressed() {
  return (kcan_data.steeringWheelButtons >> 3) % 2;
}

bool telephonePressed() {
  return (kcan_data.steeringWheelButtons >> 4) % 2;
}

bool voicePressed() {
  return (kcan_data.steeringWheelButtons >> 5) % 2;
}

bool rotatePressed() {
  return (kcan_data.steeringWheelButtons >> 6) % 2;
}

bool diskPressed() {
  return (kcan_data.steeringWheelButtons >> 7) % 2;
}

//  ## Convert scroller buttons into bools ##
bool pausePressed() {
  return scroller_data.buttons % 2;
}

bool nextSongPressed() {
  return (scroller_data.buttons >> 1) % 2;
}

bool prevSongPressed() {
  return (scroller_data.buttons >> 2) % 2;
}

bool clickPressed() {
  return (scroller_data.buttons >> 3) % 2;
}

bool rightPressed() {
  return (scroller_data.buttons >> 4) % 2;
}

bool leftPressed() {
  return (scroller_data.buttons >> 5) % 2;
}


// ### LCD screen functions
// displays engineTemp, enginePower, engineTorque, batteryVoltage, clutchPressed, brakePressed, throttlePercentage, steeringPosition
void drawMixedDash() {
  char outputStr[12];

  u8g2.firstPage();
  do {
    u8g2.drawStr(1, 8, "Enginetemp.:");
    getEngineTempStr(outputStr);
    u8g2.drawUTF8(81, 8, outputStr);

    // Calculated engine power from torque and rpm
    u8g2.drawStr(1, 18, "Enginepower:");
    getEnginePowerStr(outputStr);
    u8g2.drawStr(81, 18, outputStr);

    u8g2.drawStr(1, 28, "Torque     :");
    getEngineTorqueStr(outputStr);
    u8g2.drawStr(81, 28, outputStr);

    u8g2.drawStr(1, 38, "Battvoltage:");
    getBatteryVoltageStr(outputStr);
    u8g2.drawStr(81, 38, outputStr);

    // Clutch status
    u8g2.drawButtonUTF8(32, 50, U8G2_BTN_HCENTER | U8G2_BTN_BW1 | (kcan_data.clutchPressed ? U8G2_BTN_INV : 0), 62,  0,  1, "Clutch" );

    // Brake status
    u8g2.drawButtonUTF8(96, 50, U8G2_BTN_HCENTER | U8G2_BTN_BW1 | (kcan_data.brakePressed ? U8G2_BTN_INV : 0), 62,  0,  1, "Brake" );

    // Throttle position
    u8g2.drawBox(0, 55, round(kcan_data.throttlePercentage * 128.0f), 5);

    // Steering position
    int16_t barWidth = -round(kcan_data.steeringPosition * 64.0f);
    if(barWidth >= 0) {
      u8g2.drawBox(64, 61, barWidth, 3);
    } else {
      u8g2.drawBox(64 + barWidth, 61, abs(barWidth), 3);
    }
    
  } while( u8g2.nextPage() );
}

// displays fuel levels
void drawFuelInfo() {
  // max fuel is about 62 liters which we will map to a height of 32 pixels (about half of the display)
  int16_t level1Height = 63 - (int16_t)round(kcan_data.fuelLevel1 * (32.0f/62.0f));
  int16_t level2Height = 63 - (int16_t)round(kcan_data.fuelLevel2 * (32.0f/62.0f));
  int16_t textHeight = 52; // alternatively: this puts text above fuel level but may collide with new text on top: level1Height < level2Height ? level1Height - 1 : level2Height - 1;
  char outputStr[15];

  u8g2.firstPage();
  do {
    u8g2.drawStr(1, 8, "Range:");
    getRangeStr(outputStr);
    u8g2.drawStr(43, 8, outputStr);
    
    u8g2.drawStr(1, 18, " Avg.:");
    getAvgConsumptionStr(outputStr);
    u8g2.drawStr(43, 18, outputStr);

    getAvgSpeedStr(outputStr);
    u8g2.drawStr(43, 28, outputStr);

    u8g2.setDrawColor(2); // XOR draw mode
    getFuelLevelStr(outputStr, 1);
    u8g2.drawStr(1, textHeight, outputStr);

    getFuelPercentageStr(outputStr);
    u8g2.drawStr(48, textHeight, outputStr);

    getFuelLevelStr(outputStr, 2);
    u8g2.drawStr(93, textHeight, outputStr);

    // fuel level 1
    u8g2.drawTriangle(0,level1Height, 0,64, 128,64);
    // fuel level 2
    u8g2.drawTriangle(0,level1Height, 128,level2Height, 128,64);
    u8g2.setDrawColor(1); // normal draw mode
  } while( u8g2.nextPage() );
}
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

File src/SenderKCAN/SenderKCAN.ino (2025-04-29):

#include <esp_now.h>
#include <WiFi.h>
#include <SPI.h>
#include <mcp2515_can.h>
#include <SD.h>
#include <FS.h>

#define CAN_CS_PIN 5

#define ESP_NOW_CHANNEL 1 // if you change this you have to change this on all devices

#define SD_MISO 13
#define SD_SCLK 14
#define SD_CS 15
#define SD_MOSI 27
#define HSPI_FRQ 32000000

// Replace with the MAC address of your receiver! (see serial output of the receiver)
uint8_t LCDreceiverAddress[] = {0x58, 0xBF, 0x25, 0x9D, 0xF5, 0x70};

uint16_t dateYear = 0;
uint8_t dateMonth;
uint8_t dateDay;
uint8_t dateHour;
uint8_t dateMinute;
uint8_t dateSecond;

typedef struct kcan_data_t {
  bool clutchPressed;
  bool brakePressed;
  bool reversed;
  uint8_t steeringWheelButtons; // each bit one button (use functions below): 2^0=VolumeUp, 2^1=VolumeDown, 2^2=UpButton, 2^3=DownButton, 2^4=TelephoneButton, 2^5=VoiceButton, 2^6=RotateButton, 2^7=DiskButton
  uint8_t PDCsensors[8]; // in cm, order: rear-L, rear-L2, rear-R2, rear-R, front-L, front-L2, front-R2, front-R
  int16_t engineTemp; // in celcius
  int16_t wheelSpeeds[4]; // in km/h (might depend on car settings), order: front-L, front-R, rear-L, rear-R
  uint16_t speed; // in km/h (might depend on car settings)
  uint16_t engineRpm;
  uint16_t range; // in km
  uint16_t airPressEngine; // in hPa
  float fuelLevel1; // in liter
  float fuelLevel2; // in liter
  float engineTorque; // in Nm, can be negative!
  float batteryVoltage; // in volts
  float avgConsumption; // in l/100km (dependent on the car settings)
  float avgSpeed; // in km/h (dependent on the car settings)
  float throttlePercentage; // throttle from 0 (foot off paddle) to 1 (flat), also includes throttle input from cruise control
  float steeringPosition; // +1 -> fully (600°) to the left, 0 -> centered, -1 -> fully (600°) to the right
  float accelerationLong; // in m/s²
  float accelerationCross; // in m/s²
} kcan_data_t;

typedef struct sd_data_t {
  uint16_t usedMiB;
  uint16_t totalMiB;
} sd_data_t;

kcan_data_t kcan_data;
sd_data_t sd_data;
esp_now_peer_info_t receiverInfo;
esp_now_send_status_t lastSendStatus = (esp_now_send_status_t)0;

mcp2515_can CAN(CAN_CS_PIN);

SPIClass hspi(HSPI);
bool loggingModule = false;

TaskHandle_t DataTask;
TaskHandle_t SenderTask;
TaskHandle_t LoggerTask;

// called when a data package is sent
void OnDataSent(const uint8_t * mac_addr, esp_now_send_status_t status) {
  lastSendStatus = status;
  if(status != 0) {
    Serial.println("Error sending message!");
  }
}


void setup() {
  Serial.begin(115200);

  WiFi.mode(WIFI_STA);
  WiFi.setChannel(ESP_NOW_CHANNEL);
  while (!WiFi.STA.started()) {
    Serial.println("\nStarting Wifi...");
    delay(100);
  }

  // Init ESP-NOW
  if (esp_now_init() != ESP_OK) {
    Serial.println("Error initializing ESP-NOW! Restarting...");
    ESP.restart();
  }

  // Register callback message
  esp_now_register_send_cb(OnDataSent);
  
  // Register peer
  memcpy(receiverInfo.peer_addr, LCDreceiverAddress, 6);
  receiverInfo.channel = ESP_NOW_CHANNEL;  
  receiverInfo.encrypt = false;
  
  // Add peer        
  if (esp_now_add_peer(&receiverInfo) != ESP_OK){
    Serial.println("Failed to add peer! Restarting...");
    ESP.restart();
  }
  Serial.println("ESP-NOW init successful!");

  Serial.print("Sending ESP-NOW messages at a size of: ");
  Serial.println(sizeof(kcan_data));
  Serial.println();


  /* ATTENTION: We are interfacing a 100KBPS CAN bus but need to use the 200KBPS variable
     This is needed because the library expects a MCP module with a 16MHz crystal on it
     Check if your crystal (usually shiny, oval) has an 8 or 16 written on it
     if 8 --> use CAN_200KBPS          if 16 --> use CAN_100KBPS
     This also applies to other CAN bus speeds of course, always double the speed if you have an 8MHz crystal */
  while (CAN_OK != CAN.begin(CAN_200KBPS)) {
    Serial.println("CAN bus init failed! Retrying in 250...");
    delay(250);
  }
  do {
    Serial.println("Setting CAN mode to MODE_LISTENONLY");
    //  if we don't set this mode i assume that the MCP sends an acknowledge message when messages are received and the car does NOT like this AT ALL
    CAN.setMode(MODE_LISTENONLY); // this is very important!!!
  } while(CAN.getMode() != MODE_LISTENONLY);
  Serial.println("CAN bus initialized successfully\n");


  // Init SD card ( or not :) )
  hspi.begin(SD_SCLK, SD_MISO, SD_MOSI, SD_CS); // use other SPI bus for the SD card to not interrupt the MCP
  hspi.setFrequency(HSPI_FRQ);
  pinMode(SD_CS, OUTPUT);

  if(!SD.begin(SD_CS, hspi, HSPI_FRQ) || SD.cardType() == CARD_NONE) {
    Serial.println("SD card module not connected or no card inserted");
  } else {
    loggingModule = true;
    Serial.println("SD card module initialized successfully");
    Serial.printf("SD storage: %llu MiB/%llu MiB\n", SD.usedBytes() / (1024 * 1024), SD.totalBytes() / (1024 * 1024));
  }
  Serial.println();


  xTaskCreatePinnedToCore(
                    senderTaskCode, // Task function.
                    "senderTask",   // name of task.
                    5000,           // Stack size of task
                    NULL,           // parameter of the task
                    2,              // priority of the task
                    &SenderTask,    // Task handle to keep track of created task
                    0);             // pin task to core 0
  
  if(loggingModule) {
    xTaskCreatePinnedToCore(
                    loggerTaskCode, // Task function.
                    "loggerTask",   // name of task.
                    5000,           // Stack size of task
                    NULL,           // parameter of the task
                    1,              // priority of the task
                    &LoggerTask,    // Task handle to keep track of created task
                    0);             // pin task to core 0
  }

  xTaskCreatePinnedToCore(
                    dataTaskCode,   // Task function.
                    "dataTask",     // name of task.
                    10000,          // Stack size of task
                    NULL,           // parameter of the task
                    2,              // priority of the task
                    &DataTask,      // Task handle to keep track of created task
                    1);             // pin task to core 1                  
}


void loop() {
}
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

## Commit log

2025-01-16 add basic schematic layout (only screen functionality)
    [e92dashModSchematic.kicad_pcb, e92dashModSchematic.kicad_sch]
2025-01-18 fix encoder button wiring
    [e92dashModSchematic.kicad_sch]
2025-01-18 added LCD on/off functionality, added .gitignore
    [e92dashModSchematic.kicad_sch]
2025-01-21 updated CAN functionality (should work now) and extended README
    [e92dashModSchematic.kicad_sch]
2025-01-23 added CAN coversion methods (except for steering, need irl data first)
2025-01-24 added more detail on the LCD pinout
    [e92dashModSchematic.kicad_sch]
2025-01-25 added the calculation of steering wheel position
2025-01-26 extended CAN bus information in README
2025-02-01 implemented steering wheel buttons (to be optimized)
2025-02-05 fixed a MAJOR problem, some further annotations
    [SenderKCAN.ino]
2025-02-10 rudimentary encoder and menu implementation
2025-02-13 started CAD design, added SD mounting bracket
    [SD_holder.step, SenderModels.FCStd]
2025-02-14 started work on sender enclosure
    [SenderModels.FCStd]
2025-02-15 first functional version of enclosure top
    [Enclosure_top.step, SenderModels.FCStd]
2025-02-16 added lid, first testing version
    [Enclosure_bottom.step, Enclosure_top.step, SenderModels.FCStd]
2025-02-17 tweaked sender enclosure, added accessory mounts
    [Enclosure_bottom.step, Enclosure_top.step, SenderModels.FCStd]
2025-02-18 final sender enclosure tweaks, added additional mounting points
    [Enclosure_bottom.step, Enclosure_top.step, SenderModels.FCStd]
2025-02-19 start work on processing logged data via spreadsheet, added sample logs
    [graphTemplate.ods, log_1.csv, log_2.csv]
2025-02-20 basically finished spreadsheet conversion, fixed some errors in code
    [graphTemplate.ods]
2025-02-21 updated/adjusted schematic, removed unnecessary code, closes #1
    [ReceiverSchematic.kicad_pcb, ReceiverSchematic.kicad_sch, SenderSchematic.kicad_pcb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]
2025-02-22 first functional version of graph template
    [graphTemplate.ods]
2025-02-22 made graph template more solid
    [graphTemplate.ods, updatedLog.csv]
2025-02-23 small adjustments, new testing data
    [graphTemplate.ods]
2025-02-24 adjusted table for current situation
    [graphTemplate.ods, updatedLog.csv]
2025-02-25 updated data conversion to use program, graph template therefore outdated and needs to be adjusted
    [log_1.csv, log_2.csv, updatedLog.csv]
2025-02-26 adjusted conversion details, got rid of old data plotting sheet
    [graphTemplate.ods, testData.csv]
2025-02-28 added SD card cover
    [SD_cover.step, SenderModels.FCStd]
2025-02-28 fixed SD cover, updated model names
    [Enclosure_bottom.step, Enclosure_top.step, SD_cover.step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]
2025-03-01 Removed Bluetooth again, as it does not work in combination with ESP-NOW
    [ReceiverLCD.ino]
2025-03-02 added graphs and data
    [log_2.csv, log_2_converted.csv, log_3.csv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]
2025-03-03 add E92 trim hanger to mount Enclosure in car
    [E92_trim_hanger.step, SenderModels.FCStd]
2025-03-04 adjusted data collection and logging according to recent findings
    [log_2.csv, log_2_converted.csv, log_3.csv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]
2025-03-05 Updated SD cover to make it clamp flush
    [SD_cover.step, SenderModels.FCStd]
2025-03-05 updated data logging system
    [log_2025_03_04_15h_52m_27s.csv, log_2025_03_04_17h_59m_38s.csv]
2025-03-07 started receiver CAD design
    [ReceiverModels.FCStd]
2025-03-11 fix Windows file system related bug
    [log_2025_03_04_15h_52m_27s.csv, log_2025_03_04_17h_59m_38s.csv]
2025-03-12 finish LCD holder
    [LCD_mount.step, ReceiverModels.FCStd]
2025-03-13 add encoder knob
    [ReceiverModels.FCStd, encoder_knob.step]
2025-03-14 add LED ring to receiver schematic and CAD
    [LED_ring_holder.step, ReceiverModels.FCStd, ReceiverSchematic.kicad_sch]
2025-03-14 fixed LED ring holder dimensions
    [LED_ring_holder.step, ReceiverModels.FCStd]
2025-03-15 added basic LED ring code, documentation
2025-03-16 extend UI with basic LED ring controls
2025-03-17 LCD holder overhaul
    [LCD_mount.step, ReceiverModels.FCStd]
2025-03-18 add controller enclosure
    [ReceiverModels.FCStd, controller_enclosure.step]
2025-03-19 update data plotter to show min/max values, add another sample log
    [log_2025_03_17_20_22_12.csv]
2025-03-20 added more advanced LED ring implementation, shift light
2025-03-22 Upload test mounted receiver picture
2025-03-23 add velcro tie mount for receiver, small dimension fix for controller box
    [ReceiverModels.FCStd, controller_enclosure.step, velcro_ties_mount.step]
2025-03-25 add automatic switch to PDC sensor screen, switch to clearer typedefs
2025-03-26 add SD card usage info to selector screen, fixed ordering of CAN IDs, added some REAME info
    [ReceiverLCD.ino, SenderKCAN.ino]
2025-03-28 rework selector screen logic
    [ReceiverLCD.ino]
2025-04-14 removed parts of automatically switching to PDC screen as sensor values are not actually delivered as expected
2025-05-01 add scroller button support
